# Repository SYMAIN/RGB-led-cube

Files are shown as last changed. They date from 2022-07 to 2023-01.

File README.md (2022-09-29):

# RGB-led-cube

This project was created to learn more about circuit boards, electronic components, 3D printing, electricity and embedded programming. It consists of 4x4x4 RGB LEDs, each able to be turned on individually using only 6 Arduino pins by using [Shift Registers](https://en.wikipedia.org/wiki/Shift_register) and [Bit Angle Modulation](https://tiemenwaterreus.com/posts/4-bit-angle-modulating/).

cube1

Demos:

https://user-images.githubusercontent.com/73000223/192903921-adc4f65e-4e14-4fca-b12e-bf22174f0ff1.mov

https://user-images.githubusercontent.com/73000223/192928861-055b67dd-9abe-455a-9a94-8997f7c88414.mp4

Dev Notes:
[Pitch Slides](https://docs.google.com/presentation/d/1Q3SgMbCxCJnp64us6YknnfaCr0XkEVGkdK7O4LI-4xs/edit?usp=sharing)

wires1
pcb1
pcb2
3dprint1

A project inspired by Kevin Darrah on [YouTube](https://www.youtube.com/watch?v=guppB4cK3oU&list=PL0JWuCHXfJ2zXVRqFRFVq-lNt_xtCYMjx&index=5) && Malt Whiskey on [YouTube](https://www.youtube.com/watch?v=gzdSvov-5-8)

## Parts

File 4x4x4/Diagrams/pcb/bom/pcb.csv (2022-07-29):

Id | Designator | Package | Quantity | Designation | Supplier and ref
1 | R39,R23,R53,R14,R19,R47,R51,R16,R25,R21,R10,R29,R30,R20,R50,R49,R24,R28,R45,R31,R42,R26,R44,R35,R43,R48,R40,R9,R34,R7,R12,R36,R11,R38,R32,R8,R17,R37,R6,R46,R52,R13,R15,R27,R41,R18,R33,R22 | R_Axial_DIN0204_L3.6mm_D1.6mm_P5.08mm_Horizontal | 48 | 330
2 | U7,U2,U4,U6,U1,U5,U3 | SO16 | 7 | 74HC595
3 | J4,J7,J9,J14,J11,J1,J12,J8,J13,J10,J6,J5,J3 | TerminalBlock_Phoenix_MKDS-1,5-4-5.08_1x04_P5.08mm_Horizontal | 13 | Conn_01x04_Female
4 | Q1,Q2,Q4,Q3 | TO127P584H533-3 | 4 | 2N2222
5 | R4,R3,R2,R1 | R_Axial_DIN0204_L3.6mm_D1.6mm_P5.08mm_Horizontal | 4 | 1000
6 | J2 | TerminalBlock_Phoenix_PT-1,5-6-5.0-H_1x06_P5.00mm_Horizontal | 1 | Conn_01x06_Female

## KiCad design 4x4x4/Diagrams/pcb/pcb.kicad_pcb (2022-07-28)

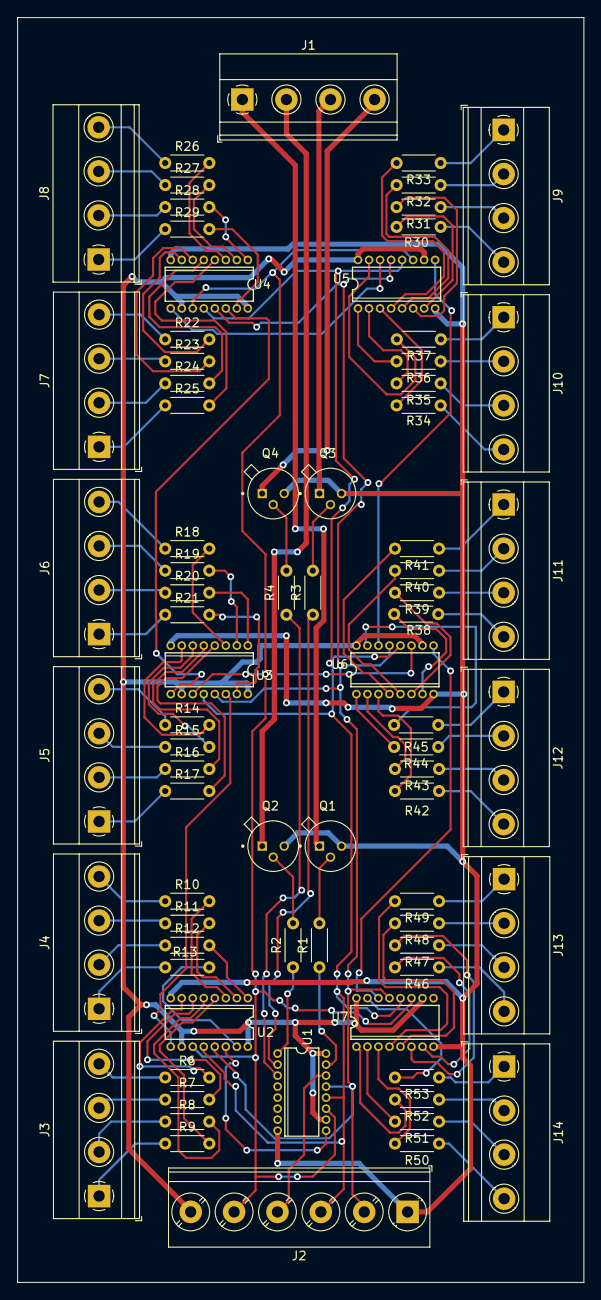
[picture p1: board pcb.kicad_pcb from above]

Board: 2 copper layers, 65.3 x 145.8 mm, 77 parts (0 on the bottom side), 120 nets.

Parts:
J1, J3, J4, J5, J6, J7, J8, J9, J10, J11, J12, J13, J14: Conn_01x04_Female; TerminalBlock_Phoenix_MKDS-1,5-4-5.08_1x04_P5.08mm_Horizont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
J2: Conn_01x06_Female; TerminalBlock_Phoenix_PT-1,5-6-5.0-H_1x06_P5.00mm_Horizontal
Q1, Q2, Q3, Q4: 2N2222; TO127P584H533-3
R1, R2, R3, R4: 1000; R_Axial_DIN0204_L3.6mm_D1.6mm_P5.08mm_Horizontal
R6, R7, R8, R9, R10, R11, R12, R13, R14, R15, R16, R17, R18, R19, R20, R21, R22, R23, R24, R25, R26, R27, R28, R29, R30, R31, R32, R33, R34, R35, R36, R37, R38, R39, R40, R41, R42, R43, R44, R45, R46, R47, R48, R49, R50, R51, R52, R53: 330; R_Axial_DIN0204_L3.6mm_D1.6mm_P5.08mm_Horizontal
U1, U2, U3, U4, U5, U6, U7: 74HC595; SO16

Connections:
GND: J2.1, Q1.3, Q2.3, Q3.3, Q4.3, U1.8 (GND), U2.8 (GND), U3.8 (GND), U4.8 (GND), U5.8 (GND), U6.8 (GND), U7.8 (GND)
unnamed: J1.1, Q1.1
unnamed: J1.2, Q2.1
unnamed: J1.3, Q3.1
unnamed: J1.4, Q4.1
unnamed: J2.2, U1.13 (~OE), U2.13 (~OE), U3.13 (~OE), U4.13 (~OE), U5.13 (~OE), U6.13 (~OE), U7.13 (~OE)
unnamed: J2.3, U1.12 (RCLK), U2.12 (RCLK), U3.12 (RCLK), U4.12 (RCLK), U5.12 (RCLK), U6.12 (RCLK), U7.12 (RCLK)
unnamed: J2.4, U1.14 (SER)
unnamed: J2.5, U1.11 (SRCLK), U2.11 (SRCLK), U3.11 (SRCLK), U4.11 (SRCLK), U5.11 (SRCLK), U6.11 (SRCLK), U7.11 (SRCLK)
unnamed: J2.6, U1.10 (~SRCLR), U1.16 (VCC), U2.10 (~SRCLR), U2.16 (VCC), U3.10 (~SRCLR), U3.16 (VCC), U4.10 (~SRCLR), U4.16 (VCC), U5.10 (~SRCLR), U5.16 (VCC), U6.10 (~SRCLR), U6.16 (VCC), U7.10 (~SRCLR), U7.16 (VCC)
unnamed: J3.1, R9.1
unnamed: J3.2, R8.1
unnamed: J3.3, R7.1
unnamed: J3.4, R6.1
unnamed: J4.1, R13.1
unnamed: J4.2, R12.1
unnamed: J4.3, R11.1
unnamed: J4.4, R10.1
unnamed: J5.1, R17.1
unnamed: J5.2, R16.1
unnamed: J5.3, R15.1
unnamed: J5.4, R14.1
unnamed: J6.1, R21.1
unnamed: J6.2, R20.1
unnamed: J6.3, R19.1
unnamed: J6.4, R18.1
unnamed: J7.1, R25.1
unnamed: J7.2, R24.1
unnamed: J7.3, R23.1
unnamed: J7.4, R22.1
unnamed: J8.1, R29.1
unnamed: J8.2, R28.1
unnamed: J8.3, R27.1
unnamed: J8.4, R26.1
unnamed: J9.1, R33.1
unnamed: J9.2, R32.1
unnamed: J9.3, R31.1
unnamed: J9.4, R30.1
unnamed: J10.1, R37.1
unnamed: J10.2, R36.1
unnamed: J10.3, R35.1
unnamed: J10.4, R34.1
unnamed: J11.1, R41.1
unnamed: J11.2, R40.1
unnamed: J11.3, R39.1
unnamed: J11.4, R38.1
unnamed: J12.1, R45.1
unnamed: J12.2, R44.1
unnamed: J12.3, R43.1
unnamed: J12.4, R42.1
unnamed: J13.1, R49.1
unnamed: J13.2, R48.1
unnamed: J13.3, R47.1
unnamed: J13.4, R46.1
unnamed: J14.1, R53.1
unnamed: J14.2, R52.1
unnamed: J14.3, R51.1
unnamed: J14.4, R50.1
unnamed: Q1.2, R1.2
unnamed: Q2.2, R2.2
unnamed: Q3.2, R3.2
unnamed: Q4.2, R4.2
unnamed: R1.1, U1.15 (QA)
unnamed: R2.1, U1.1 (QB)
unnamed: R3.1, U1.2 (QC)
unnamed: R4.1, U1.3 (QD)
unnamed: R6.2, U2.7 (QH)
unnamed: R7.2, U2.6 (QG)
unnamed: R8.2, U2.5 (QF)
unnamed: R9.2, U2.4 (QE)
unnamed: R10.2, U2.3 (QD)
unnamed: R11.2, U2.2 (QC)
unnamed: R12.2, U2.1 (QB)
unnamed: R13.2, U2.15 (QA)
unnamed: R14.2, U3.7 (QH)
unnamed: R15.2, U3.6 (QG)
unnamed: R16.2, U3.5 (QF)
unnamed: R17.2, U3.4 (QE)
unnamed: R18.2, U3.3 (QD)
unnamed: R19.2, U3.2 (QC)
unnamed: R20.2, U3.1 (QB)
unnamed: R21.2, U3.15 (QA)
unnamed: R22.2, U4.7 (QH)
unnamed: R23.2, U4.6 (QG)
unnamed: R24.2, U4.5 (QF)
unnamed: R25.2, U4.4 (QE)
unnamed: R26.2, U4.3 (QD)
unnamed: R27.2, U4.2 (QC)
unnamed: R28.2, U4.1 (QB)
unnamed: R29.2, U4.15 (QA)
unnamed: R30.2, U5.7 (QH)
unnamed: R31.2, U5.6 (QG)
unnamed: R32.2, U5.5 (QF)
unnamed: R33.2, U5.4 (QE)
unnamed: R34.2, U5.3 (QD)
unnamed: R35.2, U5.2 (QC)
unnamed: R36.2, U5.1 (QB)
unnamed: R37.2, U5.15 (QA)
unnamed: R38.2, U6.7 (QH)
unnamed: R39.2, U6.6 (QG)
unnamed: R40.2, U6.5 (QF)
unnamed: R41.2, U6.4 (QE)
unnamed: R42.2, U6.3 (QD)
unnamed: R43.2, U6.2 (QC)
unnamed: R44.2, U6.1 (QB)
unnamed: R45.2, U6.15 (QA)
unnamed: R46.2, U7.7 (QH)
unnamed: R47.2, U7.6 (QG)
unnamed: R48.2, U7.5 (QF)
unnamed: R49.2, U7.4 (QE)
unnamed: R50.2, U7.3 (QD)
unnamed: R51.2, U7.2 (QC)
unnamed: R52.2, U7.1 (QB)
unnamed: R53.2, U7.15 (QA)
unnamed: U1.9 (QH'), U2.14 (SER)
unnamed: U2.9 (QH'), U3.14 (SER)
unnamed: U3.9 (QH'), U4.14 (SER)
unnamed: U4.9 (QH'), U5.14 (SER)
unnamed: U5.9 (QH'), U6.14 (SER)
unnamed: U6.9 (QH'), U7.14 (SER)

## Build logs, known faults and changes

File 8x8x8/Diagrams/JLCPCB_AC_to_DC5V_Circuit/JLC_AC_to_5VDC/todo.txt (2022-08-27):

get new 3p footprint
reduce current from 1A->600mA somehow
route pcb, check trace sizes

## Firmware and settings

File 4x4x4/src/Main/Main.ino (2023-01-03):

// This code was made for the Arduino Mega2560.
// Anything related to output registers (PORTxx) and SPI pins will need to be changed if using a different Arduino

unsigned char defeatTheCrumbyPreprocessor;
// https://forum.arduino.cc/t/tccr1a-was-not-declared-in-this-scope/177826/4

// The Carry
// https://www.kevindarrah.com/download/8x8x8/RGB_CubeV12_BitwiseFix.ino
// https://www.youtube.com/watch?v=xmScytz9y0M

/**
  * What is ours:
  *   - the animations
  *   - the implementation of the button into the animations
  *   - the specific implementation of the BAM and Multiplexing to work with our cube
  *     - (modified the order the data was sent out, changed which Arduino registers were used)
  *
  * What isn't ours:
  *   - the concepts of SPI, BAM, multiplexing, and LED array manipulation itself 
  *
  */

#include <SPI.h> // SPI Library used to clock data out to the shift registers

//pin connections- the #define tag will replace all instances of "latchPin" in your code with A1 (and so on)
#define latch_pin 11 // aka PB5 / PORTB5. This was found on the schematics of the Arduino Mega2560. 
#define latchPinBIN 0b00100000 // this is the internal representation of turning PORTB5 on, aka the latch pin.
#define blankPin 8 // aka PH5 / PORTH5
#define blankPinBIN 0b00100000 // this is the internal representation of turning PH5 on

#define buttonPin 7 // the pin where the pushbutton is for switching animations

#define data_pin 51 // The SPI-MOSI pinout on the Arduino Mega. Varies between Arduinos.
#define clock_pin 52 // The SPI-SCK pinout on the Arduino Mega. Varies between Arduinos.


// BLANK: Blue, pin 8
// LATCH: Yellow, pin 11
// DATA: Orange, pin 51
// CLOCK: green, pin 52

int shift_out;
byte anode[4]; // The data for grounding the LEDs

//This is how the brightness for every LED is stored,

byte red0[8], red1[8], red2[8], red3[8];
byte blue0[8], blue1[8], blue2[8], blue3[8];
byte green0[8], green1[8], green2[8], green3[8];

int level = 0;                //keeps track of which level we are shifting data to
int anodelevel = 0;           //this increments through the anode levels
int BAM_Bit, BAM_Counter = 0; // Bit Angle Modulation variables to keep track of things

int animationToPlay = 0;
bool stopAnimation = false; // for stopping animation early with the button
int buttonState = LOW;

unsigned long start; //for a millis timer to cycle through the animations

void setup()
{

  Serial.begin(9600);

  SPI.setBitOrder(MSBFIRST);           //Most Significant Bit First
  SPI.setDataMode(SPI_MODE0);          // Mode 0 Rising edge of data, keep clock low
  SPI.setClockDivider(SPI_CLOCK_DIV2); //Run the data in at 16MHz/2 - 8MHz

  noInterrupts(); // kill interrupts until everybody is set up

  //Timer 1 to refresh the cube
  TCCR1A = B00000000;
  TCCR1B = B00001011;

  TIMSK1 = B00000010;
  OCR1A = 30;

  // Grounding data for each layer/level
  anode[0]=0b00000001;
  anode[1]=0b00000010;
  anode[2]=0b00000100;
  anode[3]=0b00001000;
  
  pinMode(latch_pin, OUTPUT); //Latch
  pinMode(data_pin, OUTPUT);  //MOSI DATA
  pinMode(clock_pin, OUTPUT); //SPI Clock
  pinMode(blankPin, OUTPUT); //Output Enable  important to do this last, so LEDs do not flash on boot up
  //digitalWrite(blankPin, HIGH);
  SPI.begin();                //start up the SPI library
  interrupts();               //let the show begin, this lets the multiplexing start
}

void loop()
{ 
  Serial.println(animationToPlay);

  if (animationToPlay == 0){
    while(!stopAnimation){
      sparkles();
    }
  }
  else if (animationToPlay == 1){
    while(!stopAnimation){
      fireFireworks();
    }
  }
  else if (animationToPlay == 2){
    animationToPlay = -1;
  }

  animationToPlay ++;
 
  if (stopAnimation){
    stopAnimation = false;
    delay(500);
  }


}

void updateButton(){
  buttonState = digitalRead(buttonPin);
  //Serial.println(buttonState);

  if (buttonState == HIGH){
    Serial.println("Button pressed~!~");
    stopAnimation = true;
  }
}

/** void LED(int row, int column, int level, byte red, byte green, byte blue)
  * 
  * A function to set a specific LED to light up with a specific intesity of red/green/blue.
  * 
  * @param level, int. The z-axis or layer the LED is on.
  * @param row, int. The index of the LED row. Supports 0-3. For getting a byte from the byte array. (aka led0, led1, led2, led3)
  * @param column, int. The index of the led in the row to light up. Supports 0-3. For accessing a bit in a byte.
  * @param red, byte. Controls bit angle modulation for the color red. Only the 4 least significant bits are used.
  * @param green, byte. Controls bit angle modulation for the color green. Only the 4 least significant bits are used.
  * @param blue, byte. Controls bit angle modulation for the color blue. Only the 4 least significant bits are used.
  *
  */
void LED(int row, int column, int level, byte red, byte green, byte blue){ 

  // error handling
  if ((level > 3) || (level < 0) || (row > 3) || (row < 0) || (column > 3) || (column < 0)){
    return;
  }

  int whichbyte = int(((level * 16) + (row * 4) + column) / 8);

  int wholebyte = (level * 16) + (row * 4) + column;

  bitWrite(red0[whichbyte], wholebyte - (8 * whichbyte), bitRead(red, 0));
  bitWrite(red1[whichbyte], wholebyte - (8 * whichbyte), bitRead(red, 1));
  bitWrite(red2[whichbyte], wholebyte - (8 * whichbyte), bitRead(red, 2));
  bitWrite(red3[whichbyte], wholebyte - (8 * whichbyte), bitRead(red, 3));

  bitWrite(green0[whichbyte], wholebyte - (8 * whichbyte), bitRead(green, 0));
  bitWrite(green1[whichbyte], wholebyte - (8 * whichbyte), bitRead(green, 1));
  bitWrite(green2[whichbyte], wholebyte - (8 * whichbyte), bitRead(green, 2));
  bitWrite(green3[whichbyte], wholebyte - (8 * whichbyte), bitRead(green, 3));

  bitWrite(blue0[whichbyte], wholebyte - (8 * whichbyte), bitRead(blue, 0));
  bitWrite(blue1[whichbyte], wholebyte - (8 * whichbyte), bitRead(blue, 1));
  bitWrite(blue2[whichbyte], wholebyte - (8 * whichbyte), bitRead(blue, 2));
  bitWrite(blue3[whichbyte], wholebyte - (8 * whichbyte), bitRead(blue, 3));
}

// A debug toggle to allow the sending of a piece of data to check for errors in the code/circuit
bool bruteForce = false;

// The BAM timer itself.
ISR(TIMER1_COMPA_vect)
{
  // Blank everything while we change some stuff
  //PORTD |= blankPinBIN;//Blank pin HIGH (aka disable outputs)

  // for calculating the brightness using BAM
  // you can think of BAM_Bit as the brightness for BAM: on for 1 tick, off for 2, on for 4, on for 8, etc....
  if (BAM_Counter == 8)
    BAM_Bit++;
  else if (BAM_Counter == 24)
    BAM_Bit++;
  else if (BAM_Counter == 56)
    BAM_Bit++;

  BAM_Counter++;

  // Here, we send out data based off of the BAM_Bit, which determines the duration.
  switch (BAM_Bit)
  {
  // 1 tick
  case 0:
    if (!bruteForce){
      // We shift out B/G/R data in this specific order due to how the circuit is wired up.
      // Residual data will go to the shift registers in a daisy chain
      for (shift_out = level; shift_out < level + 2; shift_out++)
        SPI.transfer(blue0[shift_out]);
      for (shift_out = level; shift_out < level + 2; shift_out++)
        SPI.transfer(green0[shift_out]);
      for (shift_out = level; shift_out < level + 2; shift_out++)
        SPI.transfer(red0[shift_out]);
    }

    else{
      // Brute forced data. A visualization of what the above for loops do.
      SPI.transfer(0b00000001);
      SPI.transfer(0b00000000);
      SPI.transfer(0b00000000);
      SPI.transfer(0b00000000);
      SPI.transfer(0b00000000);
      SPI.transfer(0b00000000);
    }

    break;
  // 2 ticks
  case 1:
    if (!bruteForce){
      for (shift_out = level; shift_out < level + 2; shift_out++)
        SPI.transfer(blue1[shift_out]);
      for (shift_out = level; shift_out < level + 2; shift_out++)
        SPI.transfer(green1[shift_out]);
      for (shift_out = level; shift_out < level + 2; shift_out++)
        SPI.transfer(red1[shift_out]);
    }

    else{
      SPI.transfer(0b00000001);
      SPI.transfer(0b00000000);
      SPI.transfer(0b00000000);
      SPI.transfer(0b00000000);
      SPI.transfer(0b00000000);
      SPI.transfer(0b00000000);
    }
    break;
  // 4 ticks
  case 2:
    if (!bruteForce){
      for (shift_out = level; shift_out < level + 2; shift_out++)
        SPI.transfer(blue2[shift_out]);
      for (shift_out = level; shift_out < level + 2; shift_out++)
        SPI.transfer(green2[shift_out]);
      for (shift_out = level; shift_out < level + 2; shift_out++)
        SPI.transfer(red2[shift_out]);
    }

    else{
      SPI.transfer(0b00000001);
      SPI.transfer(0b00000000);
      SPI.transfer(0b00000000);
      SPI.transfer(0b00000000);
      SPI.transfer(0b00000000);
      SPI.transfer(0b00000000);
    }
    break;
  // 8 ticks
  case 3:
    if (!bruteForce){
      for (shift_out = level; shift_out < level + 2; shift_out++)
        SPI.transfer(blue3[shift_out]);
      for (shift_out = level; shift_out < level + 2; shift_out++)
        SPI.transfer(green3[shift_out]);
      for (shift_out = level; shift_out < level + 2; shift_out++)
        SPI.transfer(red3[shift_out]);
    }

    else{
      SPI.transfer(0b00000001);
      SPI.transfer(0b00000000);
      SPI.transfer(0b00000000);
      SPI.transfer(0b00000000);
      SPI.transfer(0b00000000);
      SPI.transfer(0b00000000);
    }

    // Hit the upper limit for ticks. Resets ticks back to 0.
    if (BAM_Counter == 120)
    {
      BAM_Counter = 0;
      BAM_Bit = 0;
    }
    break;
  }
  
  //SPI.transfer(0b11111111);
  SPI.transfer(anode[anodelevel]); //finally, send out the anode level byte

  // PORTD |= latchPinBIN;//Latch pin HIGH
  // PORTD &= ~(latchPinBIN);//Latch pin LOW

  // Update data in shift registers by latching the pins
  digitalWrite(latch_pin, HIGH);
  digitalWrite(latch_pin, LOW);

  // turn everything back on by disabling blanks
  //PORTD &= ~(blankPinBIN);//Latch pin LOW

  // Increment the anode level for multiplexing
  anodelevel++;

  // Increment the level to change which LED data in the array will be shifted out
  level = level + 2;

  // Resets info when upper limit is reached
  if (anodelevel == 4)
    anodelevel = 0;
  if (level == 8)
    level = 0;
  //pinMode(blankPin, OUTPUT);
}

// ANIMATIONS ***** ANIMATIONS ***** ANIMATIONS ***** ANIMATIONS ***** ANIMATIONS ***** ANIMATIONS //

void tracer(){
  for (int j = 0; j < 4; j ++){
    for (int i = 0; i < 4; i ++){
      LED(i, 0, j, 15, 0, 0);
      updateButton();
      if (stopAnimation){
        clean();
        return;
      }
      delay(100);
      clean();
    }
    for (int i = 0; i < 4; i ++){
      LED(3, i, j, 0, 15, 0);
      updateButton();
      if (stopAnimation){
        clean();
        return;
      }
      delay(100);
      clean();
    }
    for (int i = 3; i != -1; i ++){
      LED(i, 3, j, 0, 0, 15);
      updateButton();
      if (stopAnimation){
        clean();
        return;
      }
      delay(100);
      clean();
    }
    for (int i = 3; i != -1; i ++){
      LED(0, i, j, 5, 5, 5);
      updateButton();
      if (stopAnimation){
        clean();
        return;
      }
      delay(100);
      clean();
    }
  }
}

void fireFireworks(){
  // start pos
  int startX = random(4);
  int startY = random(4);

  // line
  for (int i = 0; i < 4; i ++){
    // trail
    LED(startX, startY, i - 1, 5, 0, 0);
    LED(startX, startY, i - 2, 1, 0, 0);

    // missle
    LED(startX, startY, i, 0, 0, 10);
    
    updateButton();
    if (stopAnimation){
      clean();
      return;
    }

    delay(300);
    clean();
  }

  // explosion phase1
  LED(startX, startY, 3, 15, 7, 0);
  LED(startX + 1, startY, 3, 15, 7, 0);
  LED(startX - 1, startY, 1, 15, 7, 0);
  LED(startX, startY + 1, 3, 15, 7, 0);
  LED(startX, startY - 1, 2, 15, 7, 0);
  updateButton();
  if (stopAnimation){
    clean();
    return;
  }
  delay(200);
  clean();

  // explosion phase2
  LED(startX, startY, 2, 15, 15, 0);
  LED(startX + 1, startY, 2, 15, 15, 0);
  LED(startX - 1, startY, 0, 15, 15, 0);
  LED(startX, startY + 1, 2, 15, 15, 0);
  LED(startX, startY - 1, 1, 15, 15, 0);
  updateButton();
  if (stopAnimation){
    clean();
    return;
  }
  delay(200);
  clean();
  
  // wait 1s between fireworks
  updateButton();
  if (stopAnimation){
    clean();
    return;
  }
  delay(1000);

  return;
}

void sparkles(){
  LED(random(4), random(4), random(4), random(8) + 8, random(8), random(8));
  LED(random(4), random(4), random(4), random(8), random(8) + 8, random(8));
  LED(random(4), random(4), random(4), random(8), random(8), random(8) + 8);
  updateButton();
  if (stopAnimation){
    clean();
    return;
  }
  delay(300);
  clean();
}

void launchMissles(){
  // start pos
  int startX = 1 + random(2);
  int startZ = 1 + random(2);
  // line
  for (int i = 0; i < 4; i ++){
    // trail
    if (i > 0){
      LED(startX, i - 1, startZ, 7, 0, 0);
    }
    // missle
    LED(startX, i, startZ, 0, 0, 15);

    updateButton();
    if (stopAnimation){
      clean();
      return;
    }

    delay(200);
    clean();
  }
  // explosion
  LED(startX, 2, startZ, random(15), random(15), random(15));
  LED(startX, 3, startZ, random(15), random(15), random(15));
  LED(startX, 3, startZ + 1, random(15), random(15), random(15));
  LED(startX, 3, startZ - 1, random(15), random(15), random(15));
  LED(startX + 1, 3, startZ, random(15), random(15), random(15));
  LED(startX - 1, 3, startZ, random(15), random(15), random(15));

  updateButton();
  if (stopAnimation){
    clean();
    return;
  }

  delay(200);
  clean();

  // falling
  LED(startX, 2, startZ - 1, random(7), random(7), random(7));
  LED(startX, 3, startZ - 1, random(7), random(7), random(7));
  LED(startX, 3, startZ, random(7), random(7), random(7));
  LED(startX + 1, 3, startZ - 1, random(7), random(7), random(7));
  LED(startX - 1, 3, startZ - 1, random(7), random(7), random(7));

  updateButton();
  if (stopAnimation){
    clean();
    return;
  }
  
  delay(200);
  clean();
}

void allBlue(){
  // add
  for (int i = 0; i < 4; i++)
    for (int j = 0; j < 4; j++)
      for (int k = 0; k < 4; k++)
        LED(i, j, k, 0, 0, 15);
}

void allGreen(){
  // blue
  for (int i = 0; i < 4; i++)
    for (int j = 0; j < 4; j++)
      for (int k = 0; k < 4; k++)
        LED(i, j, k, 0, 15, 0);
}

void allRed(){
  // blue
  for (int i = 0; i < 4; i++)
    for (int j = 0; j < 4; j++)
      for (int k = 0; k < 4; k++)
        LED(i, j, k, 15, 0, 0);
}

void clean()
{
  int ii, jj, kk;
  for (ii = 0; ii < 4; ii++)
    for (jj = 0; jj < 4; jj++)
      for (kk = 0; kk < 4; kk++)
        LED(ii, jj, kk, 0, 0, 0);
}

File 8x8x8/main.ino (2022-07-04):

// Works, although there is some weird behaviour between the timer and the loop() function. 
// It looks like the CPU may be bottlenecking operations here. 
// OCR1A timer was slowed down from 30 -> 300, making it 10x slower than in the 4x4x4.
// I believe it is a CPU bottleneck due to the fact that setting the timer to 30 makes the loop() code execute significantly slower. 
// However, setting it to 300 creates identical performance to code without the timer. 

// This code was made for the Arduino Nano.
// Source (pick the Type-C version): https://www.aliexpress.com/item/32241679858.html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

unsigned char defeatTheCrumbyPreprocessor;
// https://forum.arduino.cc/t/tccr1a-was-not-declared-in-this-scope/177826/4

// The Carry
// https://www.kevindarrah.com/download/8x8x8/RGB_CubeV12_BitwiseFix.ino
// https://www.youtube.com/watch?v=xmScytz9y0M

#include <SPI.h> // SPI Library used to clock data out to the shift registers

//pin connections
#define latch_pin 9 // aka D9. Any pin should work, though try to avoid D10, as it looks like it is another SPI pin used for incoming communications.
#define data_pin 11 // D11. The SPI-MOSI pinout on the Arduino Nano. Varies between Arduinos.
#define clock_pin 13 // D13. The SPI-SCK pinout on the Arduino Nano. Varies between Arduinos.

/*
The data for grounding the LEDs
Each byte for of data represents the data to send out to make a specific level (z-axis) turn on
i.e. : anode[0] is 0b00000001. This contains data to turn on the power for the leds on the bottom level.
*/
byte anode[8]; 

/*
This is how the brightness for every LED is stored.
Each bit in the arrays represents an led in the 8x8x8 cube.
For example, looking at red0[64], (8 leds * 8 leds * 8 leds) = (64 bytes * 8 bits per byte)

To control the brightness, multiple of these byte arrays are used.
Using red0[], you can specify which LED to turn on for 1 unit of time.
With red1[], you can specify which LED to turn on for 2 units of time.
With red2[], you can specify which LED to turn on for 4 units of time.
With red3[], 8 units of time. 
The total time to complete a loop is 15 units of time.

If you wanted to turn on the reds in an LED for ~50% of the time, you'd need to hit 7 or 8 units of time per loop.
In order to hit 7 units, you can set red0[], red1[], and red2[] to on. (1 unit of time + 2 + 4)
To get 8 units of time, you can set red3[] to on (8 units of time)
*/
byte red0[64], red1[64], red2[64], red3[64];
byte blue0[64], blue1[64], blue2[64], blue3[64];
byte green0[64], green1[64], green2[64], green3[64];

/*
Determines if the data sent should be for red0[], red1[], red2[], or red3[]
(Basically controls the brightness inside of the BAM)
Kevin's equivalent variable is BAM_Bit
Values are [0,3]
*/
int brightnessIndex = 0;

/*
Is a global counter to track how many times the timer has executed.
Is used for tracking time to switch between brightnesses inside the timer/BAM.
Kevin's equivalent variable is BAM_Counter
*/
int timerCounter = 0;

// The level to shift data to during BAM. Values are [0,7]
int level = 0;

// Animation support variable.
bool firstRun = true;

// Startup the SPI library and pins
void setup(){

    Serial.begin(9600);

    // messy, but works
    // Retrieves data to power a certain level of LEDs to power. 
    anode[0] = 0b00000001;
    anode[1] = 0b00000010;
    anode[2] = 0b00000100;
    anode[3] = 0b00001000;
    anode[4] = 0b00010000;
    anode[5] = 0b00100000;
    anode[6] = 0b01000000;
    anode[7] = 0b10000000;

    SPI.setBitOrder(MSBFIRST);           //Most Significant Bit First
    SPI.setDataMode(SPI_MODE0);          // Mode 0 Rising edge of data, keep clock low
    SPI.setClockDivider(SPI_CLOCK_DIV2); //Run the data in at 16MHz/2 - 8MHz

    noInterrupts(); // kill interrupts until everybody is set up

    // Timer 1 to refresh the cube.
    TCCR1A = B00000000;
    TCCR1B = B00001011;

    TIMSK1 = B00000010;
    OCR1A = 300;
    
    pinMode(latch_pin, OUTPUT); //Latch
    pinMode(data_pin, OUTPUT);  //MOSI DATA
    pinMode(clock_pin, OUTPUT); //SPI Clock
    
    SPI.begin();                //start up the SPI library
    interrupts();               //let the show begin, this lets the multiplexing start
}

void loop(){
    // Clear data on first run.
    if (firstRun){
        clear();
    }

    // Animations Here ------------------------------
    allOn();
    // Animations End -------------------------------
    
    // Animation support variable. Turn it off after first run.
    firstRun = false;
}
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

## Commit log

2022-01-03 change clock/data pins to work with SPI
2022-01-03 Timer is function, basic BAM outlined
2022-01-03 add SPI tester, it doesnt work
2022-01-09 SPI fixed, don't plug in wires into the wrong pins! No software changes.
2022-01-10 before rewrite of timer function
2022-01-12 add notable LED commands for later study
2022-01-13 add blanking. No major software changes. Remember that LEDs have different resistances!
2022-01-13 change timer
2022-01-20 change data shifting order to work with our circuit
2022-01-23 testing data inside vs outside timer
2022-01-23 rm LED calls
2022-01-23 verify that data is finished setting before doing timer stuffs
2022-01-23 forgot brackets around for loop
2022-01-23 mirror the anode pattern just in case
2022-01-24 resolve color pin
2022-01-25 minimize chances of errors on Main
    [Main.ino]
2022-01-25 fix LED multiple issues
    [Main.ino]
2022-01-25 revert timer
2022-01-25 multiple LEDs fixed
2022-01-25 add tracer animation
2022-01-25 revert to working code
    [Main.ino]
2022-01-25 readd fireworks and tracer
2022-01-25 add error handling to LED
    [Main.ino]
2022-01-25 get animations ready to integrate with button
2022-01-26 add LED function comment
2022-01-26 button working
2022-06-28 added diagrams
    [Quad 1.kicad_pcb, Quad 1.kicad_sch]
2022-06-28 rearranged files
    [Quad 1.kicad_pcb, Quad 1.kicad_sch]
2022-06-29 fixed diamgram quad 1 wiring
    [Quad 1.kicad_sch, Quad 2-3.kicad_pcb, Quad 2-3.kicad_sch]
2022-06-29 connected latch and clock wires in diagram
    [Quad 1.kicad_sch, Quad 2-3.kicad_pcb, Quad 2-3.kicad_sch]
2022-06-29 Finished quad 2-3
    [Quad 1.kicad_sch, Quad 2-3.kicad_sch]
2022-06-29 created 4x4x4 pcb
    [pcb.kicad_pcb, pcb.kicad_sch]
2022-07-01 revised quad 1 diagram
    [Quad 1.kicad_sch, Quad 2-3.kicad_sch, pcb.kicad_sch]
2022-07-01 add breaker schematic
    [breaker.kicad_pcb, breaker.kicad_sch]
2022-07-01 minor change
    [breaker.kicad_pcb, breaker.kicad_sch]
2022-07-03 add functioning SPI code
2022-07-05 Add sample AC switch. Start DC transistor switch.
    [DC_Transistor_Switch.kicad_pcb, DC_Transistor_Switch.kicad_sch, breaker.kicad_pcb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]
2022-07-05 add some components to AC breaker circuit
    [DC_Transistor_Switch.kicad_pcb, DC_Transistor_Switch.kicad_sch, breaker.kicad_pcb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]
2022-07-07 laying out 3d model of pcb
    [pcb.kicad_pcb, pcb.kicad_sch]
2022-07-07 add prototype convertor circuit
    [AC_to_DC5V_Circuit.kicad_pcb, AC_to_DC5V_Circuit.kicad_sch, breaker.kicad_sch]
2022-07-07 fix small mistake
    [AC_to_DC5V_Circuit.kicad_sch]
2022-07-08 finish general layout for pcb
    [Quad 1.kicad_sch, Quad 2-3.kicad_sch, pcb.kicad_pcb]
2022-07-12 small correction to dc-
    [AC_to_DC5V_Circuit.kicad_sch]
2022-07-12 layout pcb complete
    [pcb.kicad_pcb, pcb.kicad_sch]
2022-07-27 add final 4x4x4 pcb
    [pcb.kicad_pcb]
2022-07-27 review pcb
    [pcb.kicad_pcb, pcb.kicad_sch]
2022-07-27 fix? pcb
    [pcb.kicad_pcb]
2022-07-27 reroute some wires
    [pcb-B_Cu.gbr, pcb-B_Mask.gbr, pcb-B_Paste.gbr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]
2022-07-28 fix all DRC errors
    [pcb-B_Cu.gbr, pcb-B_Mask.gbr, pcb-B_Paste.gbr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]
2022-07-28 cleanup tracks/vias
    [pcb.kicad_pcb]
2022-07-28 create gerber files
    [pcb-B_Cu.gbr, pcb-B_Mask.gbr, pcb-B_Paste.gbr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]
2022-07-28 git add .
    [pcb.kicad_pcb]
2022-07-28 fixed wired connection pcb
    [pcb.kicad_pcb]
2022-07-29 minor changes
    [pcb-B_Cu.gbr, pcb-B_Mask.gbr, pcb-B_Paste.gbr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]
2022-08-02 add notes
    [AC_to_DC5V_Circuit.kicad_sch]
2022-08-22 start AC->DC5V Circuit
    [JLC_AC_to_5VDC.kicad_pcb, JLC_AC_to_5VDC.kicad_sch]
2022-08-27 initial sketch finished
    [AC_to_DC5V_Circuit.kicad_sch, JLC_AC_to_5VDC.kicad_pcb, JLC_AC_to_5VDC.kicad_sch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]
